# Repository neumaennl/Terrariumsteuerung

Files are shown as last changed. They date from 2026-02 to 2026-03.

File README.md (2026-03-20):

# Steuerungsskript für mein Terrarium

Die Steuerung läuft hauptsächlich auf einem [ESP32-C3 SuperMini mit Display](https://de.aliexpress.com/item/1005007929382296.html).

Daran angeschlossen sind:

- [SHT40](https://sensirion.com/de/produkte/katalog/SHT40) (vorher [GYBMEP BME280](https://42project.net/shop/sensoren/temperatursensoren/temperatur-feuchtigkeits-luftdruck-i2c-sensor/)) Sensor für Luftfeuchtigkeit und Temperatur (kommuniziert über [I²C](https://de.wikipedia.org/wiki/I%C2%B2C))
- 2 [KY-019](https://www.elektronik-kompendium.de/sites/praxis/bauteil_relaisboard.htm) Relais Module, um die Stromversorgung für Lüfter und Beregnungsanlage zu steuern
- 2 4-Pin CPU Lüfter

Auf einem Raspberry Pi 2 läuft eine Web GUI, über die historische Daten angezeigt werden und Einstellungen verändert werden können. Dazu kommuniziert der Raspberry Pi mit dem ESP32 via REST Schnittstelle. Dieser Teil ist allerdings vollkommen optional und für die eigentliche Steuerung absolut nicht notwendig.

## Autostart

Damit das Skript garantier immer läuft, wurde ein systemd Service erstellt.  
Dazu `terrarium.service` nach `/etc/systemd/system/` kopieren.  
Dann über `sudo systemctl daemon-reload` systemd neu laden.  
Mit `sudo systemctl enable terrarium.service` den Dienst aktivieren (damit er beim hochfahren startet) und wenn gewünscht per `sudo systemctl start terrarium.service` sofort starten.

Optional können für die Historie Umgebungsvariablen im Service gesetzt werden:

- `TERRARIUM_RETENTION_DAYS` (Standard: `31`) löscht nur Daten, die älter als X Tage sind.
- `TERRARIUM_RECENT_WINDOW_DAYS` (Standard: `3`) definiert, wie lange Daten in hoher Auflösung gespeichert werden.
- `TERRARIUM_RECENT_RESOLUTION_SECONDS` (Standard: `30`) Auflösung innerhalb des Recent-Fensters.
- `TERRARIUM_ARCHIVE_RESOLUTION_SECONDS` (Standard: `900`) Auflösung fuer ältere Daten.
- `TERRARIUM_MAX_DB_ROWS` begrenzt die Gesamtzahl Datensaetze (Standard wird aus obigen Werten berechnet).

Beispiel in `terrarium.service` unter `[Service]`:

```ini
Environment=TERRARIUM_RETENTION_DAYS=31
Environment=TERRARIUM_RECENT_WINDOW_DAYS=3
Environment=TERRARIUM_RECENT_RESOLUTION_SECONDS=30
Environment=TERRARIUM_ARCHIVE_RESOLUTION_SECONDS=900
Environment=TERRARIUM_MAX_DB_ROWS=12000
```

## Abhängigkeiten

- [offizieller SSD1306 Display Treiber](https://www.google.com/search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)
- [BME280 Treiber](https://github.com/robert-hh/BME280/blob/master/bme280_float.py)
- [SHT40 Treiber](https://github.com/jposada202020/MicroPython_SHT4X/blob/master/micropython_sht4x/sht4x.py)

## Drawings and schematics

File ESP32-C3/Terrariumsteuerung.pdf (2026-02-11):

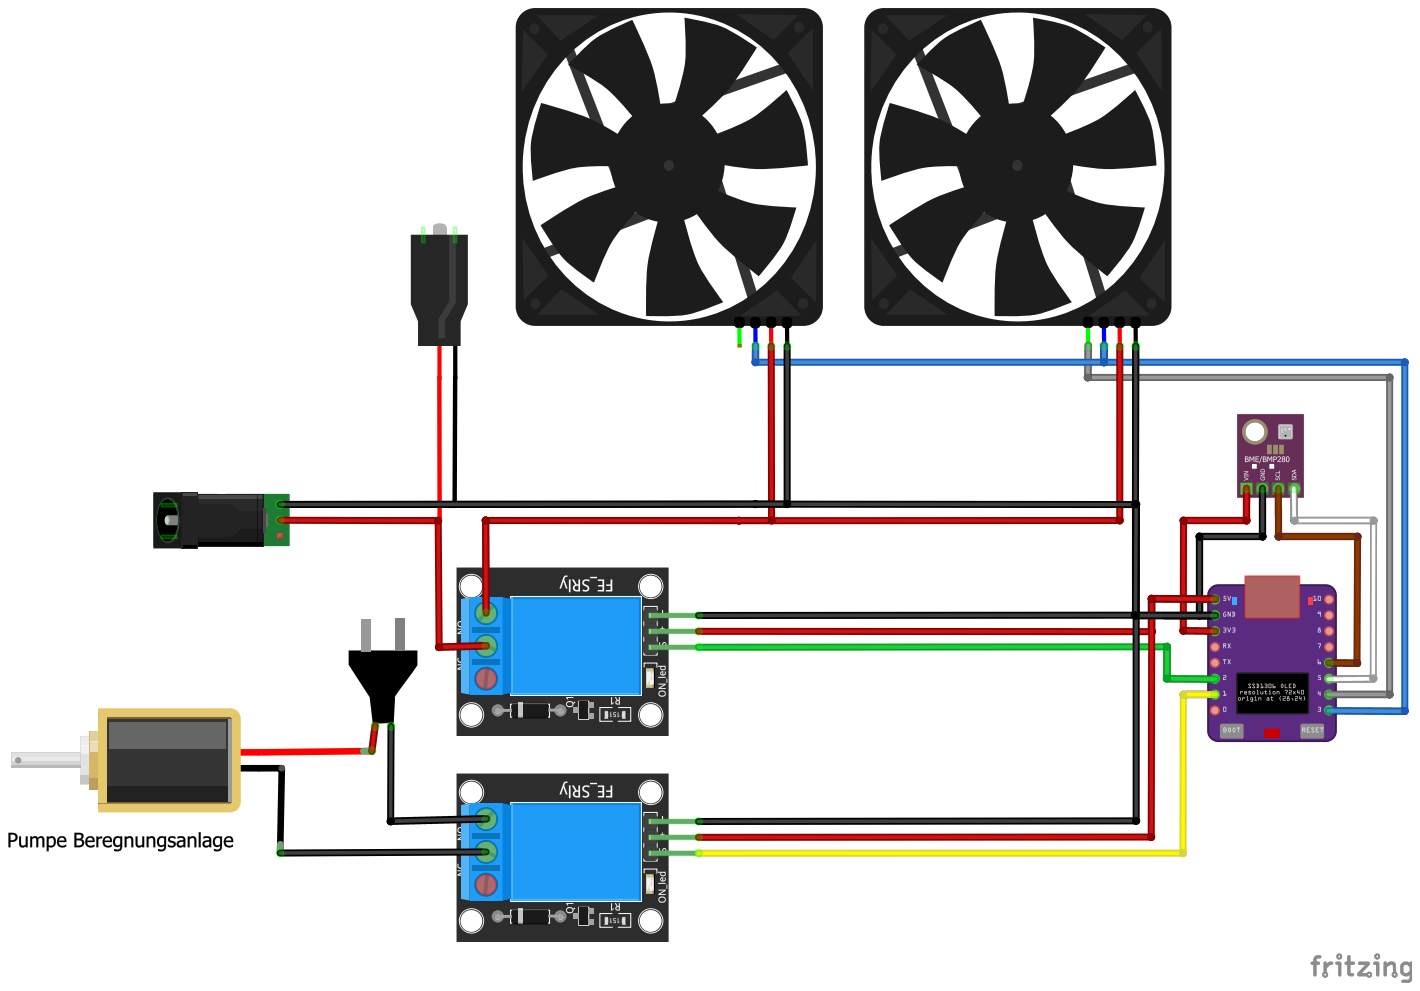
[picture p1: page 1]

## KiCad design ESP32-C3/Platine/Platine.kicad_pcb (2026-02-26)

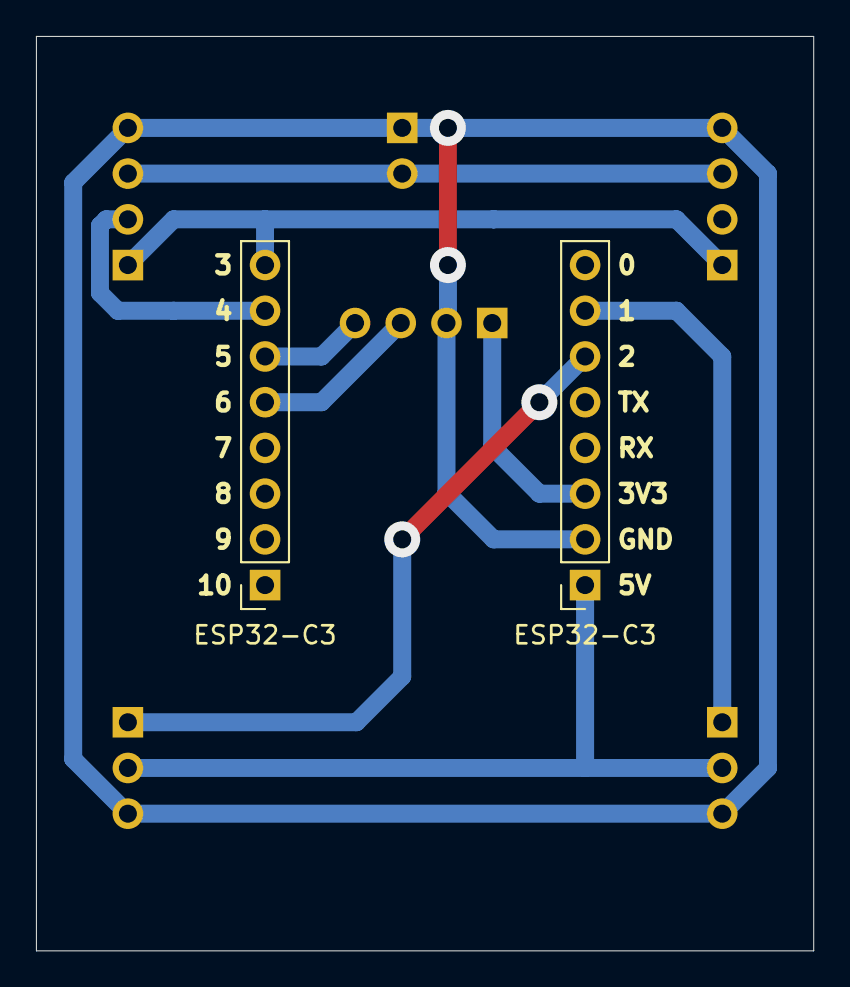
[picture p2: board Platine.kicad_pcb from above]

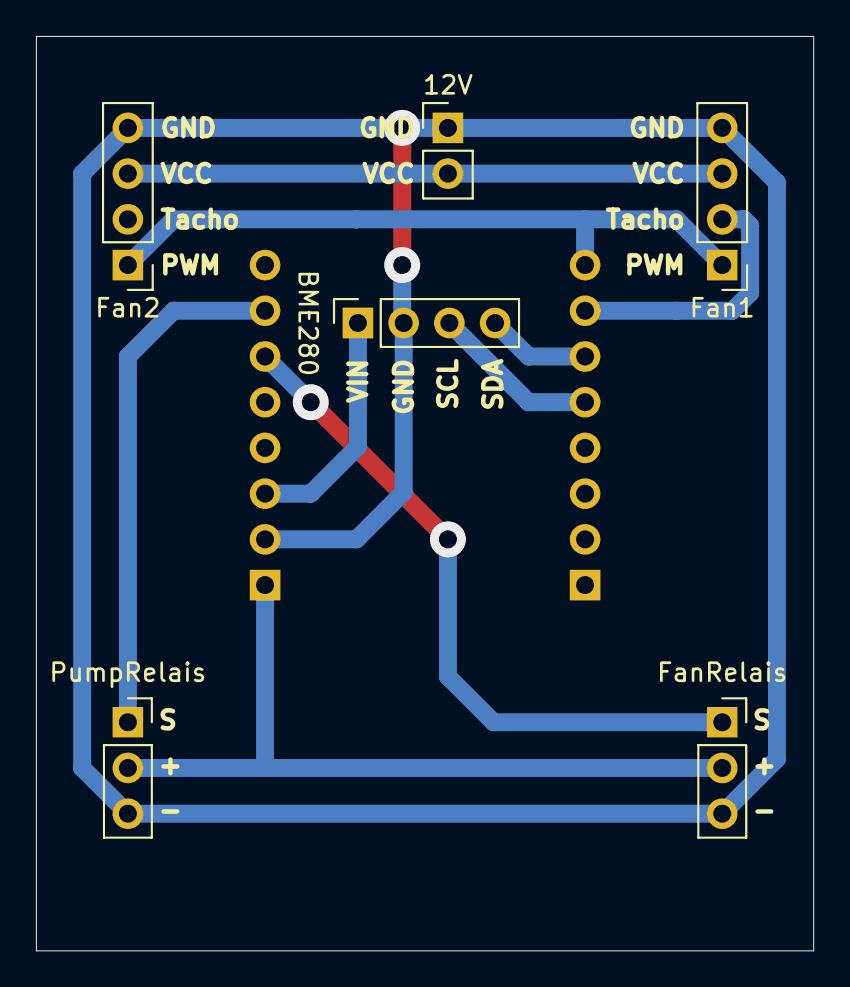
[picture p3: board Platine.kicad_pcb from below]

Board: 2 copper layers, 43.2 x 50.8 mm, 8 parts (6 on the bottom side), 10 nets.

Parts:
12V: 12V; PinHeader_1x02_P2.54mm_Vertical
BME280: BME280; PinSocket_1x04_P2.54mm_Vertical
ESP32-C3: ESP32-C3 left; PinSocket_1x08_P2.54mm_Vertical
ESP32-C3#2: ESP32-C3 right; PinSocket_1x08_P2.54mm_Vertical
Fan1: Fan 1; PinHeader_1x04_P2.54mm_Vertical
Fan2: Fan 2; PinHeader_1x04_P2.54mm_Vertical
FanRelais: Fan Relais; PinSocket_1x03_P2.54mm_Vertical
PumpRelais: Pump Relais; PinSocket_1x03_P2.54mm_Vertical

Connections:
3V3: BME280.1, ESP32-C3#2.3
5V: ESP32-C3#2.1, FanRelais.2, PumpRelais.2
12V: 12V.2, Fan1.3, Fan2.3
Fan_PWM: ESP32-C3.8, Fan1.1, Fan2.1
Fan_Relais: ESP32-C3#2.6, FanRelais.1
Fan_Tacho: ESP32-C3.7, Fan1.2
GND: 12V.1, BME280.2, ESP32-C3#2.2, Fan1.4, Fan2.4, FanRelais.3, PumpRelais.3
Pump_Relais: ESP32-C3#2.7, PumpRelais.1
SCL: BME280.3, ESP32-C3.5
SDA: BME280.4, ESP32-C3.6

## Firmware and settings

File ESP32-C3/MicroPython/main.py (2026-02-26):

"""
Main entry point for Terrarium Controller on ESP32-C3.

Handles:
- WiFi connection
- NTP time synchronization
- Display initialization
- Starting controller and web server
"""

import asyncio
import machine
import network
import json
import time
import os
from ntp_sync import log_print as print

# WiFi credentials file
WIFI_FILE = 'wifi.json'


# MicroPython: os.path may be missing. Provide a small exists() helper using os.stat
def _exists(path):
    try:
        os.stat(path)
        return True
    except Exception:
        return False


def load_wifi_config():
    """Load WiFi configuration (SSID, password, hostname) from JSON file."""
    try:
        with open(WIFI_FILE, 'r') as f:
            config = json.load(f)
            ssid = config.get('ssid')
            password = config.get('password')
            hostname = config.get('hostname', 'terrarium')
            # Validate hostname length (max 9 chars)
            if hostname and len(hostname) > 9:
                print(f"[MAIN] Hostname too long ({len(hostname)} > 9), truncating")
                hostname = hostname[:9]
            return ssid, password, hostname
    except:
        return None, None, 'terrarium'


def save_wifi_config(ssid, password, hostname='terrarium'):
    """Save WiFi configuration to JSON file.
    
    Args:
        ssid: Network SSID
        password: Network password
        hostname: Device hostname (max 9 characters, default: 'terrarium')
    """
    # Validate and truncate hostname if needed
    if hostname and len(hostname) > 9:
        print(f"[MAIN] Hostname too long ({len(hostname)} > 9), truncating to {hostname[:9]}")
        hostname = hostname[:9]
    
    try:
        with open(WIFI_FILE, 'w') as f:
            json.dump({'ssid': ssid, 'password': password, 'hostname': hostname}, f)
        print("[MAIN] WiFi config saved")
    except Exception as e:
        print(f"[MAIN] Error saving WiFi config: {e}")


async def connect_wifi(ssid, password, hostname='terrarium', timeout=20):
    """
    Connect to WiFi network.
    
    Args:
        ssid: Network SSID
        password: Network password
        hostname: Device hostname (max 9 characters, default: 'terrarium')
        timeout: Timeout in seconds
    
    Returns:
        True if connected, False otherwise
    """
    if not ssid or not password:
        print("[MAIN] No WiFi credentials configured")
        return False
    
    try:
        wlan = network.WLAN(network.STA_IF)
        wlan.active(True)
        
        # Reduce TX power for stability
        wlan.config(txpower=15)
        
        # Set hostname (max 9 characters)
        if hostname and len(hostname) <= 9:
            try:
                network.hostname(hostname)
                print(f"[MAIN] Hostname set to: {hostname}")
            except Exception as e:
                print(f"[MAIN] Failed to set hostname: {e}")
        elif hostname:
            print(f"[MAIN] Hostname too long ({len(hostname)} > 9), skipping")
        
        print(f"[MAIN] Connecting to WiFi: {ssid}")
        wlan.connect(ssid, password)

        # Wait for connection (non-blocking)
        start = time.time()
        while not wlan.isconnected():
            if time.time() - start > timeout:
                print("[MAIN] WiFi connection timeout")
                return False
            await asyncio.sleep(0.5)

        print(f"[MAIN] WiFi connected: {wlan.ifconfig()}")
        return True
        
    except Exception as e:
        print(f"[MAIN] WiFi error: {e}")
        return False


async def sync_time():
    """Synchronize system time via NTP."""
    try:
        import ntp_sync
        
        print("[MAIN] Waiting for NTP sync...")
        
        # Try multiple times
        for attempt in range(3):
            if ntp_sync.sync_time():
                return True
            await asyncio.sleep(2)
        
        print("[MAIN] NTP sync failed, continuing anyway")
        return False
        
    except Exception as e:
        print(f"[MAIN] NTP error: {e}")
        return False


async def init_display():
    """Initialize OLED display."""
    try:
        import ssd1306
        
        # I2C for display (uses pins 5/6)
        i2c = machine.I2C(0, scl=machine.Pin(6), sda=machine.Pin(5))
        
        # Initialize display (72x40 pixels)
        oled = ssd1306.SSD1306_I2C(72, 40, i2c)
        oled.fill(0)
        oled.text('Boot...', 0, 0)
        oled.show()
        
        print("[MAIN] Display initialized")
        return oled, i2c
        
    except Exception as e:
        print(f"[MAIN] Display error: {e}")
        return None, None


async def update_display(oled, text_line1='', text_line2='', text_line3='', text_line4=''):
    """Update OLED display with status text."""
    if not oled:
        return
    
    try:
        oled.fill(0)
        y = 0
        line_height = 8
        for text in [text_line1, text_line2, text_line3, text_line4]:
            if text:
                # Truncate to fit 72px display (~9 chars)
                text = str(text)[:9]
                oled.text(text, 0, y)
                y += line_height
        oled.show()
    except Exception as e:
        print(f"[MAIN] Display update error: {e}")


async def main_loop(oled, i2c):
    """
    Main async event loop.
    Runs controller and web server concurrently.
    """
    import terrariumsteuerung as ctrl
    import webserver
    
    print("[MAIN] Starting main event loop")
    
    # Create background tasks
    controller_task = asyncio.create_task(ctrl.run(i2c, oled))
    webserver_task = asyncio.create_task(webserver.run())
    
    # Optional: Display update task
    async def display_loop():
        """Periodically update display with current values."""
        while True:
            try:
                temp = ctrl.get_temperature()
                humidity = ctrl.get_humidity()
                pump_status, pump_detail = ctrl.get_pump_status_parts()
                
                await update_display(
                    oled,
                    f"T:{temp:.1f}'C",
                    f"H:{humidity:.1f}%",
                    pump_status,
                    pump_detail
                )
            except:
                pass
            
            await asyncio.sleep(2)
    
    display_task = asyncio.create_task(display_loop())
    
    # NTP sync task - resync time twice a day
    async def ntp_sync_loop():
        """Periodically resync time with NTP server."""
        sync_interval = 12 * 3600  # 12 hours (twice per day)
        while True:
            await asyncio.sleep(sync_interval)
            try:
                print("[MAIN] Periodic NTP resync...")
                await sync_time()
            except Exception as e:
                print(f"[MAIN] NTP resync error: {e}")
    
    ntp_task = asyncio.create_task(ntp_sync_loop())
    
    # Wait for both tasks (they run until interrupted)
    try:
        await asyncio.gather(controller_task, webserver_task, display_task, ntp_task)
    except KeyboardInterrupt:
        print("[MAIN] Keyboard interrupt")
    except Exception as e:
        print(f"[MAIN] Main loop error: {e}")
    finally:
        # Cleanup
        try:
            ctrl.stop()
            webserver.stop()
        except:
            pass
        
        # Final display message
        await update_display(oled, "Stopped")


async def async_main():
    """Main async startup sequence."""
    print("\n" + "="*40)
    print("Terrariumsteuerung ESP32-C3")
    print("="*40)
    
    # 1. Initialize display
    oled, i2c = await init_display()
    await update_display(oled, "Init...")
    
    # 2. Load and connect WiFi
    ssid, password, hostname = load_wifi_config()
    if ssid:
        await update_display(oled, "Connect...")
        wifi_ok = await connect_wifi(ssid, password, hostname)
        if wifi_ok:
            await update_display(oled, "WiFi OK")
        else:
            await update_display(oled, "No WiFi")
    else:
        print("[MAIN] No WiFi SSID configured in wifi.json")
        print("[MAIN] Create wifi.json with: {\"ssid\": \"...\", \"password\": \"...\", \"hostname\": \"...\"} (hostname max 9 chars)")
        await update_display(oled, "No Config")
    
    # 3. Sync time via NTP
    await update_display(oled, "NTP...")
    await sync_time()
    
    # 4. Start main loop
    await update_display(oled, "Ready")
    await asyncio.sleep(1)
    
    await main_loop(oled, i2c)


def create_default_wifi_config():
    """Create a default wifi.json file if it doesn't exist."""
    if not _exists(WIFI_FILE):
        config = {
            'ssid': 'YourSSID',
            'password': 'YourPassword',
            'hostname': 'terrarium'
        }
        try:
            with open(WIFI_FILE, 'w') as f:
                json.dump(config, f)
            print(f"[MAIN] Created {WIFI_FILE} - please edit with your credentials")
        except Exception as e:
            print(f"[MAIN] Error creating {WIFI_FILE}: {e}")


# Entry point
create_default_wifi_config()
   
try:
    # Run async main
    asyncio.run(async_main())
except KeyboardInterrupt:
    print("\n[MAIN] Interrupted")
except Exception as e:
    print(f"[MAIN] Fatal error: {e}")
    try:
        import sys
        # MicroPython: use sys.print_exception if available
        if hasattr(sys, 'print_exception'):
            sys.print_exception(e)
        else:
            # Fallback to printing repr
            print(repr(e))
    except Exception:
        pass

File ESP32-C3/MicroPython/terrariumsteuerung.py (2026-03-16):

"""
Terrarium Controller for ESP32-C3 with MicroPython.
Manages fan, pump, and sensors with async/await pattern.
"""

import machine
import asyncio
import time
from array import array
import config
from config import get
from ntp_sync import get_current_hour, log_print as print
import bme280_float
import sht4x

# --- Thresholds (loaded from storage) ---
FAN_TARGET_HUMIDITY = 80.0
FAN_SHUTOFF_HUMIDITY = 75.0
FAN_NIGHT_START_HOUR = 21
FAN_NIGHT_END_HOUR = 7
PUMP_TRIGGER_HUMIDITY = 60.0
PUMP_SPRAY_DURATION = 15
PUMP_COOLDOWN_MINUTES = 15
PUMP_NIGHT_START_HOUR = 19
PUMP_NIGHT_END_HOUR = 8

# --- Current state for web API ---
_current_temp = 0.0
_current_humidity = 0.0
_current_rpm = 0
_current_fan_pwm = 0
_current_pump_status = ("INIT", "")

# --- Last spray time ---
_last_spray_time = 0

# --- RPM counter ---
_rpm_pulses = 0

# --- Stops & Control ---
_running = False


def _clamp_fan_target(value):
    try:
        numeric = float(value)
    except Exception:
        return FAN_TARGET_HUMIDITY
    return max(1.0, min(99.0, numeric))


def load_thresholds_from_config():
    """Load thresholds from config.json into memory."""
    global FAN_TARGET_HUMIDITY, FAN_SHUTOFF_HUMIDITY, FAN_NIGHT_START_HOUR, FAN_NIGHT_END_HOUR
    global PUMP_TRIGGER_HUMIDITY, PUMP_SPRAY_DURATION
    global PUMP_COOLDOWN_MINUTES, PUMP_NIGHT_START_HOUR, PUMP_NIGHT_END_HOUR
    
    try:
        FAN_TARGET_HUMIDITY = _clamp_fan_target(get('FAN_TARGET_HUMIDITY', FAN_TARGET_HUMIDITY))
        FAN_SHUTOFF_HUMIDITY = float(get('FAN_SHUTOFF_HUMIDITY', FAN_SHUTOFF_HUMIDITY))
        FAN_NIGHT_START_HOUR = int(get('FAN_NIGHT_START_HOUR', FAN_NIGHT_START_HOUR))
        FAN_NIGHT_END_HOUR = int(get('FAN_NIGHT_END_HOUR', FAN_NIGHT_END_HOUR))
        PUMP_TRIGGER_HUMIDITY = float(get('PUMP_TRIGGER_HUMIDITY', PUMP_TRIGGER_HUMIDITY))
        PUMP_SPRAY_DURATION = int(get('PUMP_SPRAY_DURATION', PUMP_SPRAY_DURATION))
        PUMP_COOLDOWN_MINUTES = int(get('PUMP_COOLDOWN_MINUTES', PUMP_COOLDOWN_MINUTES))
        PUMP_NIGHT_START_HOUR = int(get('PUMP_NIGHT_START_HOUR', PUMP_NIGHT_START_HOUR))
        PUMP_NIGHT_END_HOUR = int(get('PUMP_NIGHT_END_HOUR', PUMP_NIGHT_END_HOUR))
        print("[CTRL] Thresholds loaded from config.json")
    except Exception as e:
        print(f"[CTRL] Error loading thresholds: {e}")


def set_threshold_value(name, value):
    """Set threshold and save to config.json."""
    global FAN_TARGET_HUMIDITY, FAN_SHUTOFF_HUMIDITY, FAN_NIGHT_START_HOUR, FAN_NIGHT_END_HOUR
    global PUMP_TRIGGER_HUMIDITY, PUMP_SPRAY_DURATION
    global PUMP_COOLDOWN_MINUTES, PUMP_NIGHT_START_HOUR, PUMP_NIGHT_END_HOUR
    
    if name == 'FAN_TARGET_HUMIDITY':
        FAN_TARGET_HUMIDITY = _clamp_fan_target(value)
        value = FAN_TARGET_HUMIDITY
    elif name == 'FAN_SHUTOFF_HUMIDITY':
        FAN_SHUTOFF_HUMIDITY = float(value)
        value = FAN_SHUTOFF_HUMIDITY
    elif name == 'FAN_NIGHT_START_HOUR':
        FAN_NIGHT_START_HOUR = int(value)
        value = FAN_NIGHT_START_HOUR
    elif name == 'FAN_NIGHT_END_HOUR':
        FAN_NIGHT_END_HOUR = int(value)
        value = FAN_NIGHT_END_HOUR
    elif name == 'PUMP_TRIGGER_HUMIDITY':
        PUMP_TRIGGER_HUMIDITY = float(value)
    elif name == 'PUMP_SPRAY_DURATION':
        PUMP_SPRAY_DURATION = int(value)
    elif name == 'PUMP_COOLDOWN_MINUTES':
        PUMP_COOLDOWN_MINUTES = int(value)
    elif name == 'PUMP_NIGHT_START_HOUR':
        PUMP_NIGHT_START_HOUR = int(value)
    elif name == 'PUMP_NIGHT_END_HOUR':
        PUMP_NIGHT_END_HOUR = int(value)
    
    config.set(name, value)


def get_threshold_value(name):
    """Get current threshold value."""
    if name == 'FAN_TARGET_HUMIDITY':
        return FAN_TARGET_HUMIDITY
    elif name == 'FAN_SHUTOFF_HUMIDITY':
        return FAN_SHUTOFF_HUMIDITY
    elif name == 'FAN_NIGHT_START_HOUR':
        return FAN_NIGHT_START_HOUR
    elif name == 'FAN_NIGHT_END_HOUR':
        return FAN_NIGHT_END_HOUR
    elif name == 'PUMP_TRIGGER_HUMIDITY':
        return PUMP_TRIGGER_HUMIDITY
    elif name == 'PUMP_SPRAY_DURATION':
        return PUMP_SPRAY_DURATION
    elif name == 'PUMP_COOLDOWN_MINUTES':
        return PUMP_COOLDOWN_MINUTES
    elif name == 'PUMP_NIGHT_START_HOUR':
        return PUMP_NIGHT_START_HOUR
    elif name == 'PUMP_NIGHT_END_HOUR':
        return PUMP_NIGHT_END_HOUR
    return None


def reset_thresholds_to_defaults():
    """Reset thresholds to defaults and persist them."""
    defaults = config.DEFAULT_CONFIG
    for key in (
        'FAN_TARGET_HUMIDITY',
        'FAN_SHUTOFF_HUMIDITY',
        'FAN_NIGHT_START_HOUR',
        'FAN_NIGHT_END_HOUR',
        'PUMP_TRIGGER_HUMIDITY',
        'PUMP_SPRAY_DURATION',
        'PUMP_COOLDOWN_MINUTES',
        'PUMP_NIGHT_START_HOUR',
        'PUMP_NIGHT_END_HOUR',
    ):
        if key in defaults:
            set_threshold_value(key, defaults[key])
    print("[CTRL] Thresholds reset to defaults")


# --- Current state getters for web API ---
def get_temperature():
    return _current_temp

def get_humidity():
    return _current_humidity

def get_rpm():
    return _current_rpm

def get_fan_pwm():
    return _current_fan_pwm


def _format_pump_status(status):
    code, detail = status
    if detail:
        return f"{code} ({detail})"
    return code


def get_pump_status():
    return _format_pump_status(_current_pump_status)


def get_pump_status_parts():
    return _current_pump_status


def _make_pump_status(code, detail=''):
    return (str(code), str(detail) if detail else '')


# --- RPM Interrupt Handler ---
def rpm_callback(pin):
    """Callback for RPM sensor edge."""
    global _rpm_pulses
    _rpm_pulses += 1


def is_fan_night_time():
    """Check if current hour is within night time range for the fan."""
    hour = get_current_hour()
    if hour >= FAN_NIGHT_START_HOUR or hour < FAN_NIGHT_END_HOUR:
        return True
    return False


def is_pump_night_time():
    """Check if current hour is within night time range for the pump."""
    hour = get_current_hour()
    if hour >= PUMP_NIGHT_START_HOUR or hour < PUMP_NIGHT_END_HOUR:
        return True
    return False


def _run_sht4x_heater(sht_sensor, reason):
    """Run a short SHT4X heater cycle and return to high precision mode."""
    try:
        # Full 1-second heat pulse effectively evaporates condensation between infrequent cycles.
        sht_sensor.heater_power = sht4x.HEATER110mW
        sht_sensor.heat_time = sht4x.TEMP_1
        _ = sht_sensor.measurements
        sht_sensor.temperature_precision = sht4x.HIGH_PRECISION
        print(f"[CTRL] SHT4X heater cycle done ({reason})")
        return True
    except Exception as e:
        try:
            sht_sensor.temperature_precision = sht4x.HIGH_PRECISION
        except Exception:
            pass
        print(f"[CTRL] SHT4X heater error ({reason}): {e}")
        return False
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

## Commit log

2026-01-28 Fritzing Dateien hinzugefügt
    [Terrariumsteuerung.fzz]
2026-02-04 Intervalle für Datenspeicherung angepasst und Diagramm in der GUI zoombar gemacht.
2026-02-11 Schaltplan auf ESP32-C3 SuperMini mit Display umgestellt
    [Terrariumsteuerung.fzz]
2026-02-11 Readme für ESP32-C3 umgeschrieben
2026-02-15 Platine Start
    [Platine.kicad_pcb, Platine.kicad_sch]
2026-02-15 Platine hat alle Netze
    [Platine.kicad_pcb]
2026-02-20 Behandlung für Zeitzonen und Sommerzeit hinzugefügt
2026-02-20 Platine finalisiert
    [Platine.kicad_pcb]
2026-02-22 vertauschte PWM und Tacho Pins korrigiert
    [Platine.kicad_pcb]
2026-02-26 beide Varianten in einem Branch als Basis für Refactoring zu getrennten Verantwortlichkeiten
    [Platine.kicad_pcb, Platine.kicad_sch, Terrariumsteuerung.fzz]
2026-02-26 getrennte Verantwortlichkeiten für Raspberry Pi und ESP32-C3 implementiert
2026-03-05 Steuerung der Beregnungsanlage per Button hinzugefügt.
2026-03-05 Diagramm holt nun dynamisch Daten, Werte von Lüfter und Pumpe werden im Diagramm angezeigt und Speicherstatus vom ESP wird bei den Werten angezeigt.
2026-03-08 Lüfter läuft in der Nacht nicht
2026-03-11 separate Nachtzeiten für Lüfter und Pumpe
2026-03-15 Unterstützung für den SHT40 Temperatur- und Luftfeuchtigkeitssensor hinzugefügt
